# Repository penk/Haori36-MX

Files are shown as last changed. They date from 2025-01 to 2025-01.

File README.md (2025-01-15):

## Haori36-MX - 36-Key Split Monoblock Ortholinear Keyboard

Another no-frills build with per-key RGB LEDs, based on the [Choc version](https://github.com/penk/Haori36).

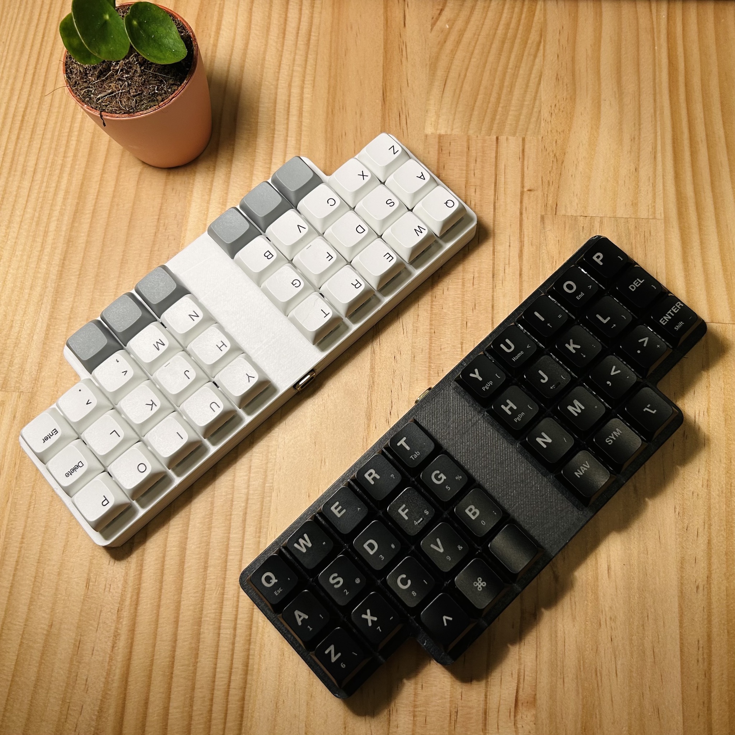
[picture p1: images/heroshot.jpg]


## Bill of Materials (BOM)

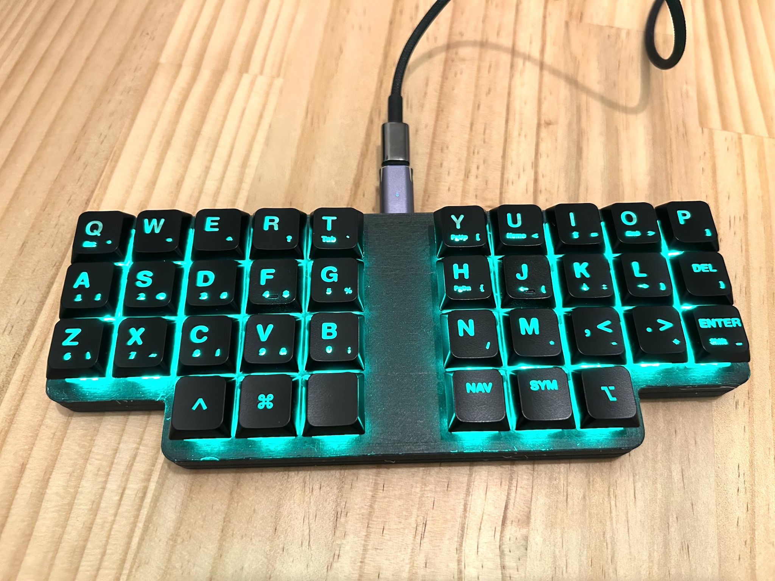
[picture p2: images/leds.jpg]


Quantity | Item
--- | ---
1 | RP2040-Zero
1 | Haori36-MX PCB
36 | MX switches and keycaps 
36 | MX Hotswap sockets
36 | 1N4148SOD-123 diodes
36 | SK6812MINI-E RGB LEDs
1 | Haori36-MX tray & plate
8 | M2×3 heat-set threaded inserts
8 | M2×8 countersunk screws

## Production Files

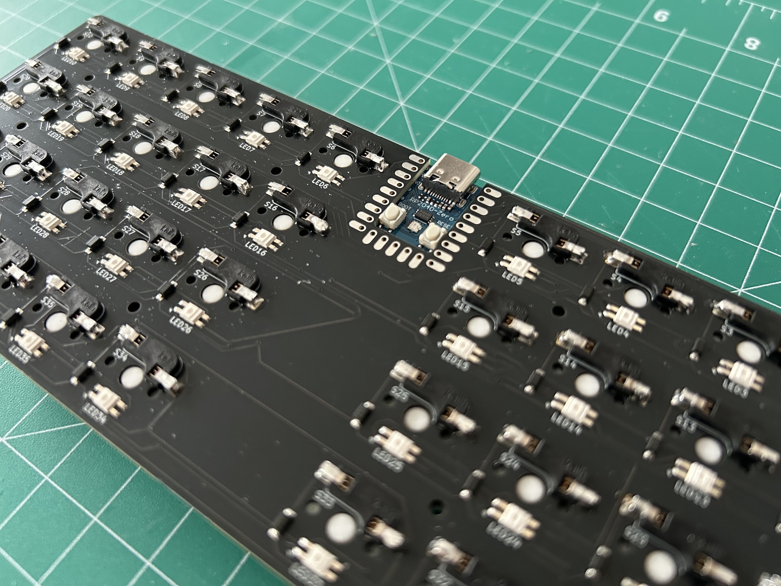
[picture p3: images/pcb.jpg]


To place an order for the Haori36-MX PCB:

- Use the Gerber files available in the [production/](production/) folder.
- The [BOM](production/BOM.csv) and [CPL](production/CPL.csv) files can optionally be used with a PCBA service —— especially if you'd prefer to avoid soldering small diodes or LEDs. 😊

All components (except the MCU) are soldered to the back (bottom) side of the board.

The complete PCB design project is available in the [kicad/](kicad/) folder.

## 3D Printable Files

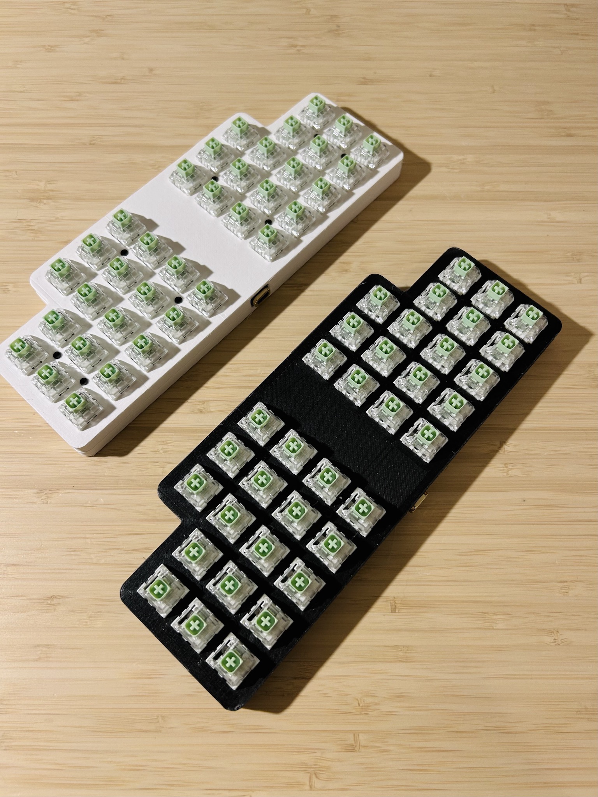
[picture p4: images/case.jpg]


Print the case and plate using the provided [STL files](case/).

## Firmware

Precompiled VIA-enabled firmware:

- Flash `penk_haori36_mx_default.uf2` under [firmware/](firmware/) to the RP2040 MCU.
- Load the [via.json](firmware/QMK/keyboards/penk/haori36_mx/via.json) file in the `Design` tab for [VIA](https://usevia.app) configuration.

The QMK source is available under [firmware/QMK/keyboards/penk/haori36_mx](firmware/QMK/keyboards/penk/haori36_mx/).

### Default Keymaps 

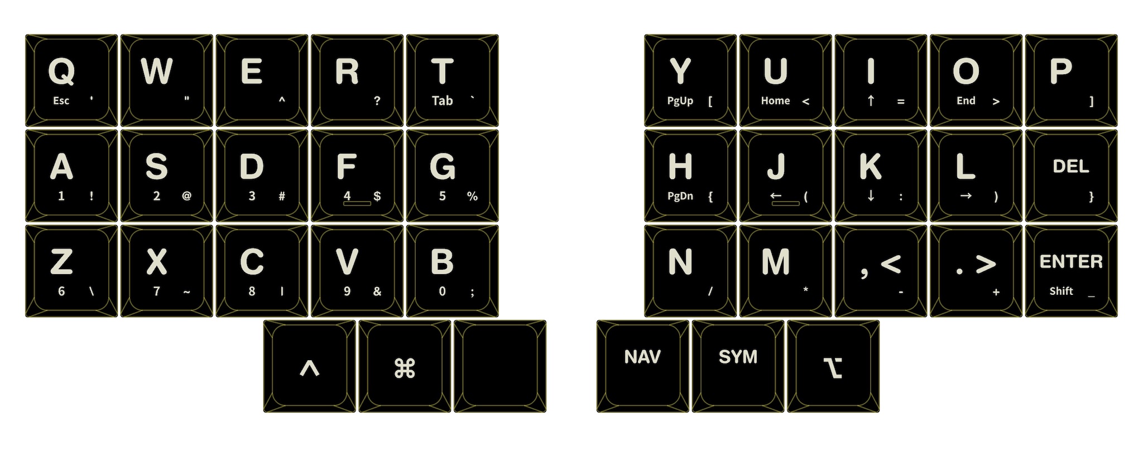
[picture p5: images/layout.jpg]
layout


The keymap is based on Rico's [rsta layout](https://github.com/rstacruz/my_qmk_keymaps/blob/main/preview.png), and the custom keycaps are made by FK Keycaps. 

You can order the same keycap set or customize yours at [https://fkcaps.com/custom/D7829J](https://fkcaps.com/custom/D7829J).

## Copyright and License
Copyright (c) 2025 Penk Chen. All rights reserved.

All files are licensed under the MIT license. For more information, see the [LICENSE](LICENSE).

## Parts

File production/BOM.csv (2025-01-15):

Designator | Footprint | Quantity | Value | LCSC Part #
D1, D10, D11, D12, D13, D14, D15, D16, D17, D18, D19, D2, D20, D21, D22, D23, D24, D25, D26, D27, D28, D29, D3, D30, D31, D32, D33, D34, D35, D36, D4, D5, D6, D7, D8, D9 | Diode_SOD-123 | 36 | Diode | C2972760
LED1, LED10, LED11, LED12, LED13, LED14, LED15, LED16, LED17, LED18, LED19, LED2, LED20, LED21, LED22, LED23, LED24, LED25, LED26, LED27, LED28, LED29, LED3, LED30, LED31, LED32, LED33, LED34, LED35, LED36, LED4, LED5, LED6, LED7, LED8, LED9 | LED_MX_6028R | 36 | MX_SK6812MINI-E | C5149201
S1, S10, S11, S12, S13, S14, S15, S16, S17, S18, S19, S2, S20, S21, S22, S23, S24, S25, S26, S27, S28, S29, S3, S30, S31, S32, S33, S34, S35, S36, S4, S5, S6, S7, S8, S9 | SW_MX_HS_CPG151101S11_1u | 36 | Keyswitch | C5156480

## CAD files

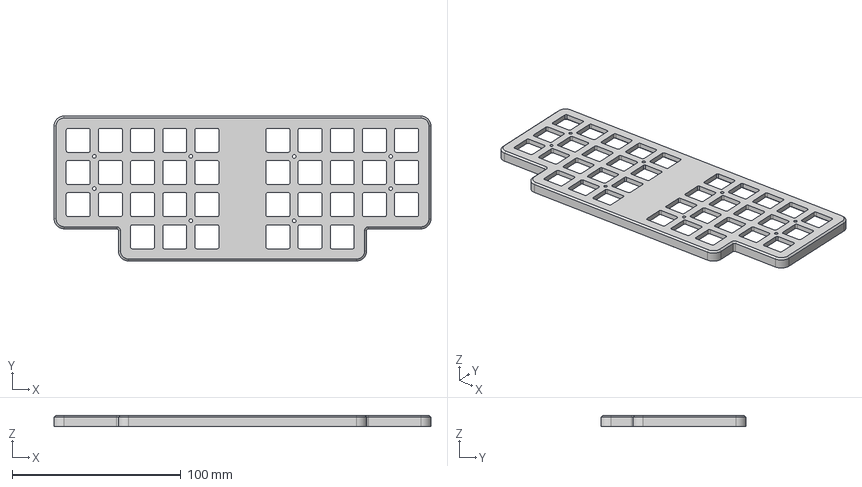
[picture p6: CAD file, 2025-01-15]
case/Haori36-MX-plate.step
223.2 x 85.9 x 6.70 mm

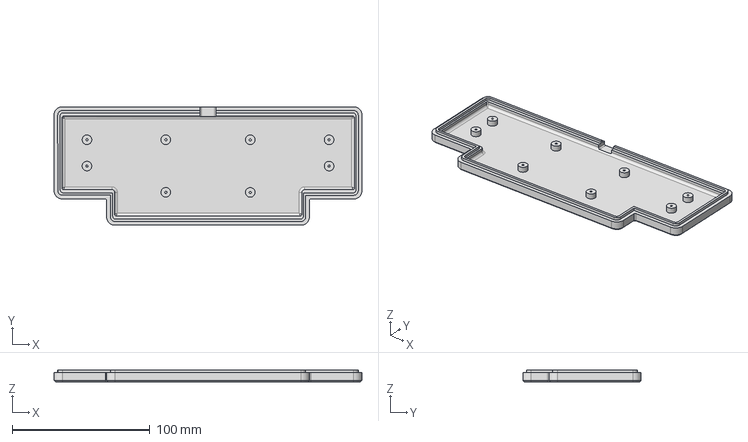
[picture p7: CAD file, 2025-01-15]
case/Haori36-MX-tray.step
223.2 x 85.9 x 8.80 mm

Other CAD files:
case/haori36-mx-plate.stl
case/haori36-mx-tray.stl

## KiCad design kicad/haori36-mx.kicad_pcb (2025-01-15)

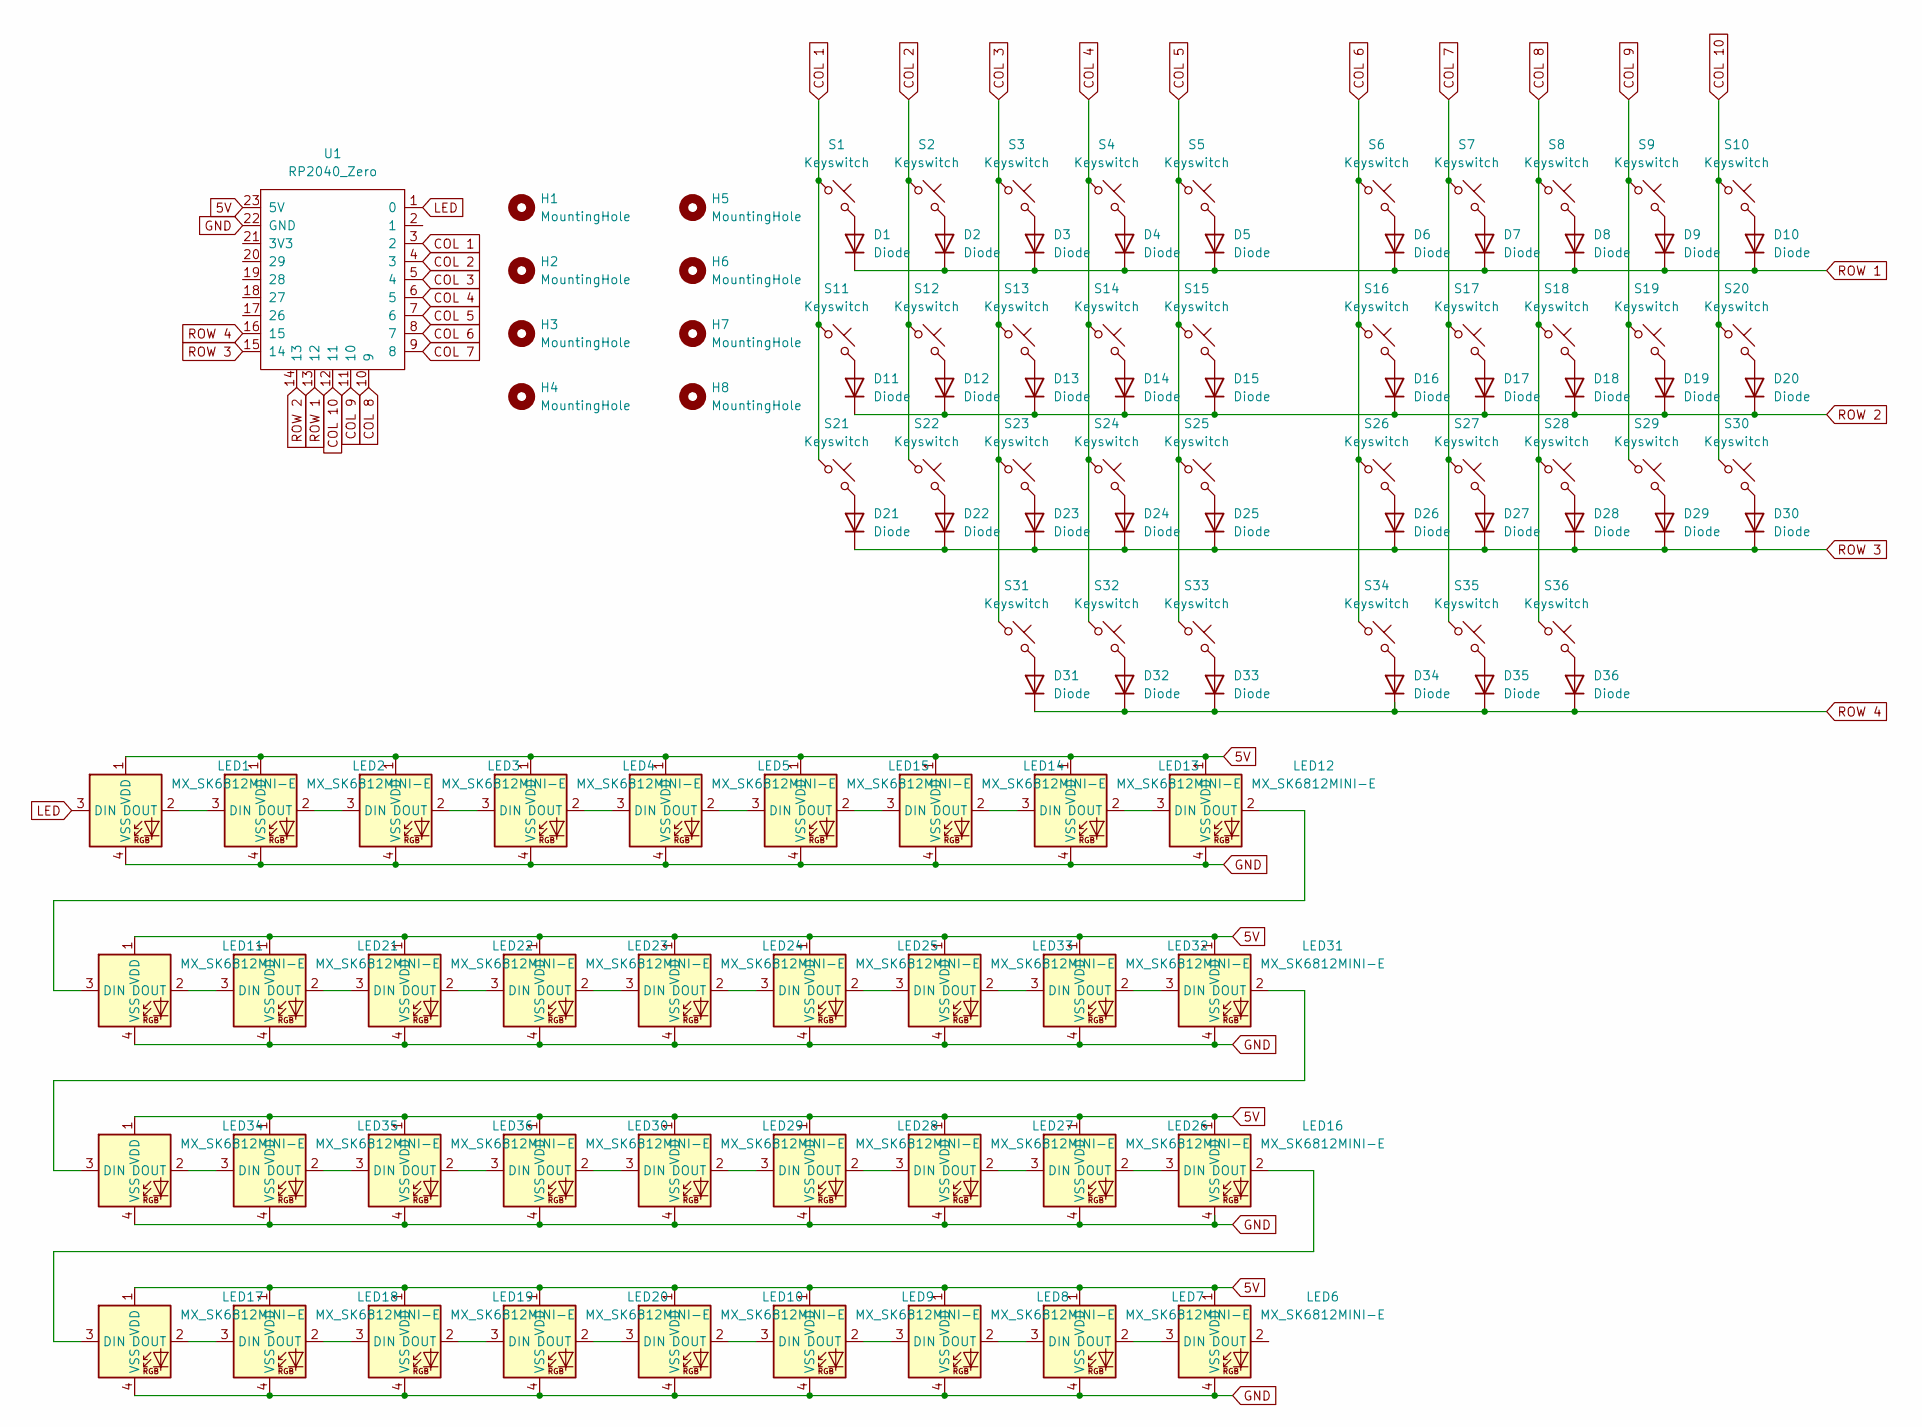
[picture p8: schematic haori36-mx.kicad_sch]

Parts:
D1, D2, D3, D4, D5, D6, D7, D8, D9, D10, D11, D12, D13, D14, D15, D16, D17, D18, D19, D20, D21, D22, D23, D24, D25, D26, D27, D28, D29, D30, D31, D32, D33, D34, D35, D36: Diode; Diode_SOD-123
H1, H2, H3, H4, H5, H6, H7, H8: MountingHole; MountingHole_2.2mm_M2
LED1, LED2, LED3, LED4, LED5, LED6, LED7, LED8, LED9, LED10, LED11, LED12, LED13, LED14, LED15, LED16, LED17, LED18, LED19, LED20, LED21, LED22, LED23, LED24, LED25, LED26, LED27, LED28, LED29, LED30, LED31, LED32, LED33, LED34, LED35, LED36: MX_SK6812MINI-E; LED_MX_6028R
S1, S2, S3, S4, S5, S6, S7, S8, S9, S10, S11, S12, S13, S14, S15, S16, S17, S18, S19, S20, S21, S22, S23, S24, S25, S26, S27, S28, S29, S30, S31, S32, S33, S34, S35, S36: Keyswitch; SW_MX_HS_CPG151101S11_1u
U1: RP2040_Zero; RP2040_Zero_holes

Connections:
5V: LED1.1 (VDD), LED2.1 (VDD), LED3.1 (VDD), LED4.1 (VDD), LED5.1 (VDD), LED6.1 (VDD), LED7.1 (VDD), LED8.1 (VDD), LED9.1 (VDD), LED10.1 (VDD), LED11.1 (VDD), LED12.1 (VDD), LED13.1 (VDD), LED14.1 (VDD), LED15.1 (VDD), LED16.1 (VDD), LED17.1 (VDD), LED18.1 (VDD), LED19.1 (VDD), LED20.1 (VDD), LED21.1 (VDD), LED22.1 (VDD), LED23.1 (VDD), LED24.1 (VDD), LED25.1 (VDD), LED26.1 (VDD), LED27.1 (VDD), LED28.1 (VDD), LED29.1 (VDD), LED30.1 (VDD), LED31.1 (VDD), LED32.1 (VDD), LED33.1 (VDD), LED34.1 (VDD), LED35.1 (VDD), LED36.1 (VDD), U1.23 (5V)
COL 1: S1.1, S11.1, S21.1, U1.3 (2)
COL 2: S2.1, S12.1, S22.1, U1.4 (3)
COL 3: S3.1, S13.1, S23.1, S31.1, U1.5 (4)
COL 4: S4.1, S14.1, S24.1, S32.1, U1.6 (5)
COL 5: S5.1, S15.1, S25.1, S33.1, U1.7 (6)
COL 6: S6.1, S16.1, S26.1, S34.1, U1.8 (7)
COL 7: S7.1, S17.1, S27.1, S35.1, U1.9 (8)
COL 8: S8.1, S18.1, S28.1, S36.1, U1.10 (9)
COL 9: S9.1, S19.1, S29.1, U1.11 (10)
COL 10: S10.1, S20.1, S30.1, U1.12 (11)
GND: LED1.4 (VSS), LED2.4 (VSS), LED3.4 (VSS), LED4.4 (VSS), LED5.4 (VSS), LED6.4 (VSS), LED7.4 (VSS), LED8.4 (VSS), LED9.4 (VSS), LED10.4 (VSS), LED11.4 (VSS), LED12.4 (VSS), LED13.4 (VSS), LED14.4 (VSS), LED15.4 (VSS), LED16.4 (VSS), LED17.4 (VSS), LED18.4 (VSS), LED19.4 (VSS), LED20.4 (VSS), LED21.4 (VSS), LED22.4 (VSS), LED23.4 (VSS), LED24.4 (VSS), LED25.4 (VSS), LED26.4 (VSS), LED27.4 (VSS), LED28.4 (VSS), LED29.4 (VSS), LED30.4 (VSS), LED31.4 (VSS), LED32.4 (VSS), LED33.4 (VSS), LED34.4 (VSS), LED35.4 (VSS), LED36.4 (VSS), U1.22 (GND)
LED: LED1.3 (DIN), U1.1 (0)
unnamed: D1.2 (A), S1.2
unnamed: D2.2 (A), S2.2
unnamed: D3.2 (A), S3.2
unnamed: D4.2 (A), S4.2
unnamed: D5.2 (A), S5.2
unnamed: D6.2 (A), S6.2
unnamed: D7.2 (A), S7.2
unnamed: D8.2 (A), S8.2
unnamed: D9.2 (A), S9.2
unnamed: D10.2 (A), S10.2
unnamed: D11.2 (A), S11.2
unnamed: D12.2 (A), S12.2
unnamed: D13.2 (A), S13.2
unnamed: D14.2 (A), S14.2
unnamed: D15.2 (A), S15.2
unnamed: D16.2 (A), S16.2
unnamed: D17.2 (A), S17.2
unnamed: D18.2 (A), S18.2
unnamed: D19.2 (A), S19.2
unnamed: D20.2 (A), S20.2
unnamed: D21.2 (A), S21.2
unnamed: D22.2 (A), S22.2
unnamed: D23.2 (A), S23.2
unnamed: D24.2 (A), S24.2
unnamed: D25.2 (A), S25.2
unnamed: D26.2 (A), S26.2
unnamed: D27.2 (A), S27.2
unnamed: D28.2 (A), S28.2
unnamed: D29.2 (A), S29.2
unnamed: D30.2 (A), S30.2
unnamed: D31.2 (A), S31.2
unnamed: D32.2 (A), S32.2
unnamed: D33.2 (A), S33.2
unnamed: D34.2 (A), S34.2
unnamed: D35.2 (A), S35.2
unnamed: D36.2 (A), S36.2
unnamed: LED1.2 (DOUT), LED2.3 (DIN)
unnamed: LED2.2 (DOUT), LED3.3 (DIN)
unnamed: LED3.2 (DOUT), LED4.3 (DIN)
unnamed: LED4.2 (DOUT), LED5.3 (DIN)
unnamed: LED6.3 (DIN), LED7.2 (DOUT)
unnamed: LED7.3 (DIN), LED8.2 (DOUT)
unnamed: LED8.3 (DIN), LED9.2 (DOUT)
unnamed: LED10.3 (DIN), LED20.2 (DOUT)
unnamed: LED9.3 (DIN), LED10.2 (DOUT)
unnamed: LED11.3 (DIN), LED12.2 (DOUT)
unnamed: LED11.2 (DOUT), LED21.3 (DIN)
unnamed: LED12.3 (DIN), LED13.2 (DOUT)
unnamed: LED13.3 (DIN), LED14.2 (DOUT)
unnamed: LED14.3 (DIN), LED15.2 (DOUT)
unnamed: LED5.2 (DOUT), LED15.3 (DIN)
unnamed: LED16.3 (DIN), LED26.2 (DOUT)
unnamed: LED16.2 (DOUT), LED17.3 (DIN)
unnamed: LED17.2 (DOUT), LED18.3 (DIN)
unnamed: LED18.2 (DOUT), LED19.3 (DIN)
unnamed: LED19.2 (DOUT), LED20.3 (DIN)
unnamed: LED21.2 (DOUT), LED22.3 (DIN)
unnamed: LED22.2 (DOUT), LED23.3 (DIN)
unnamed: LED23.2 (DOUT), LED24.3 (DIN)
unnamed: LED24.2 (DOUT), LED25.3 (DIN)
unnamed: LED25.2 (DOUT), LED33.3 (DIN)
unnamed: LED26.3 (DIN), LED27.2 (DOUT)
unnamed: LED27.3 (DIN), LED28.2 (DOUT)
unnamed: LED28.3 (DIN), LED29.2 (DOUT)
unnamed: LED29.3 (DIN), LED30.2 (DOUT)
unnamed: LED30.3 (DIN), LED36.2 (DOUT)
unnamed: LED31.3 (DIN), LED32.2 (DOUT)
unnamed: LED31.2 (DOUT), LED34.3 (DIN)
unnamed: LED32.3 (DIN), LED33.2 (DOUT)
unnamed: LED34.2 (DOUT), LED35.3 (DIN)
unnamed: LED35.2 (DOUT), LED36.3 (DIN)
ROW 1: D1.1 (K), D2.1 (K), D3.1 (K), D4.1 (K), D5.1 (K), D6.1 (K), D7.1 (K), D8.1 (K), D9.1 (K), D10.1 (K), U1.13 (12)
ROW 2: D11.1 (K), D12.1 (K), D13.1 (K), D14.1 (K), D15.1 (K), D16.1 (K), D17.1 (K), D18.1 (K), D19.1 (K), D20.1 (K), U1.14 (13)
ROW 3: D21.1 (K), D22.1 (K), D23.1 (K), D24.1 (K), D25.1 (K), D26.1 (K), D27.1 (K), D28.1 (K), D29.1 (K), D30.1 (K), U1.15 (14)
ROW 4: D31.1 (K), D32.1 (K), D33.1 (K), D34.1 (K), D35.1 (K), D36.1 (K), U1.16 (15)

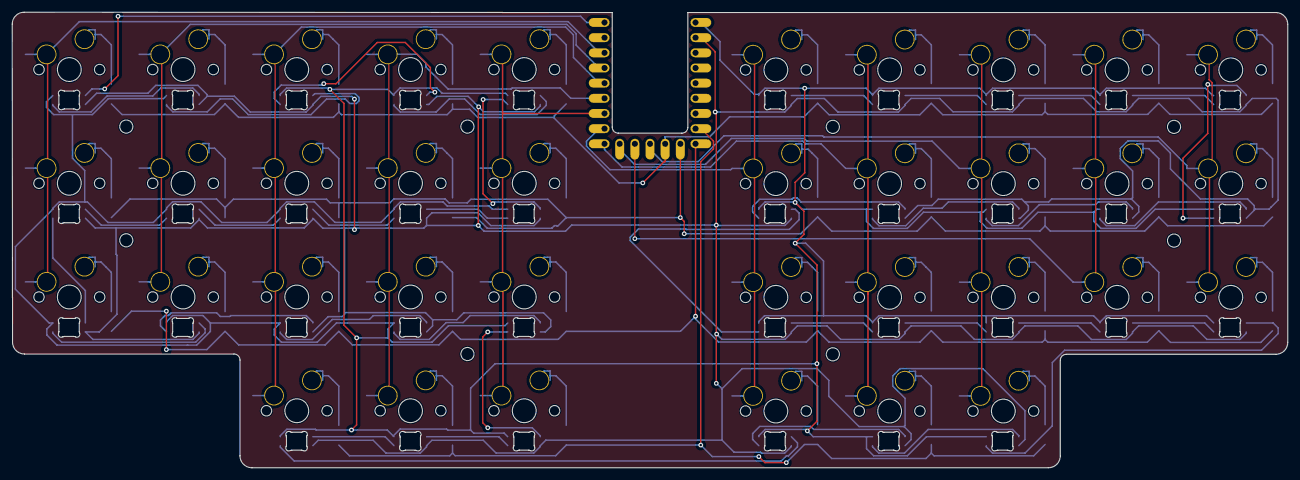
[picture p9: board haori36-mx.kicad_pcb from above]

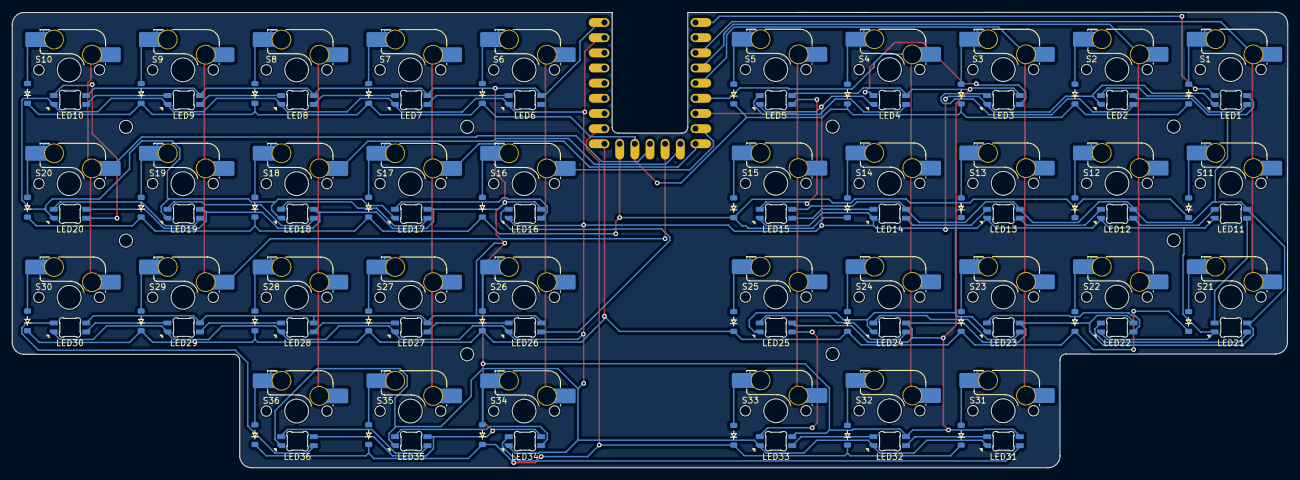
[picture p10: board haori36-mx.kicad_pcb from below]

Board: 2 copper layers, 213.6 x 76.3 mm, 117 parts (109 on the bottom side), 88 nets.
